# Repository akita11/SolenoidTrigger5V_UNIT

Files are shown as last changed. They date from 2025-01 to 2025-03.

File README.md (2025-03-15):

# SolenoidTrigger5V UNIT

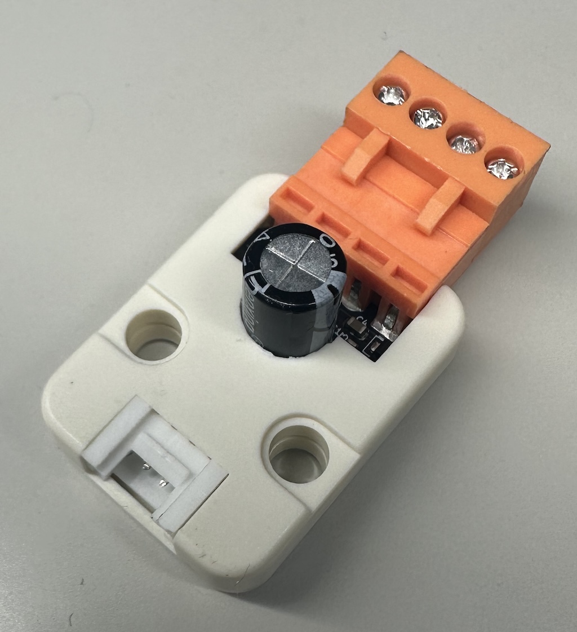
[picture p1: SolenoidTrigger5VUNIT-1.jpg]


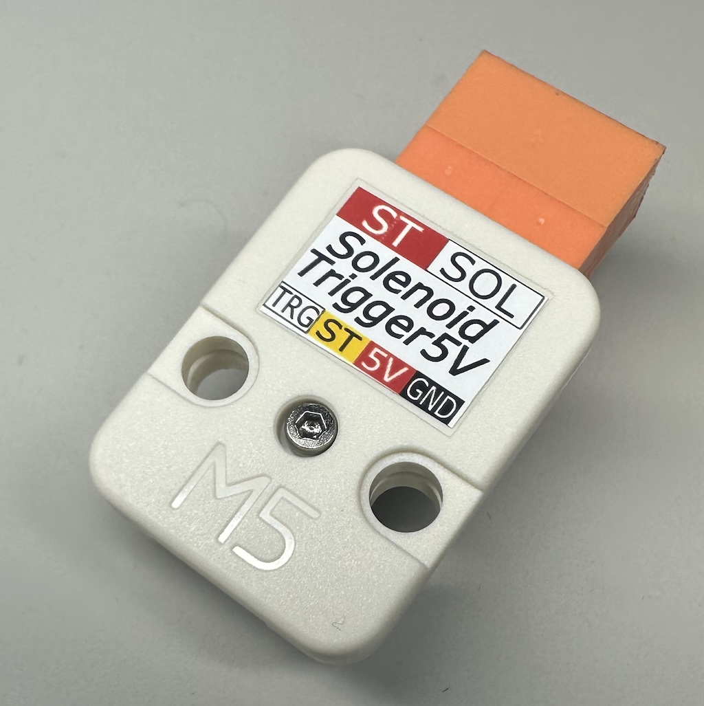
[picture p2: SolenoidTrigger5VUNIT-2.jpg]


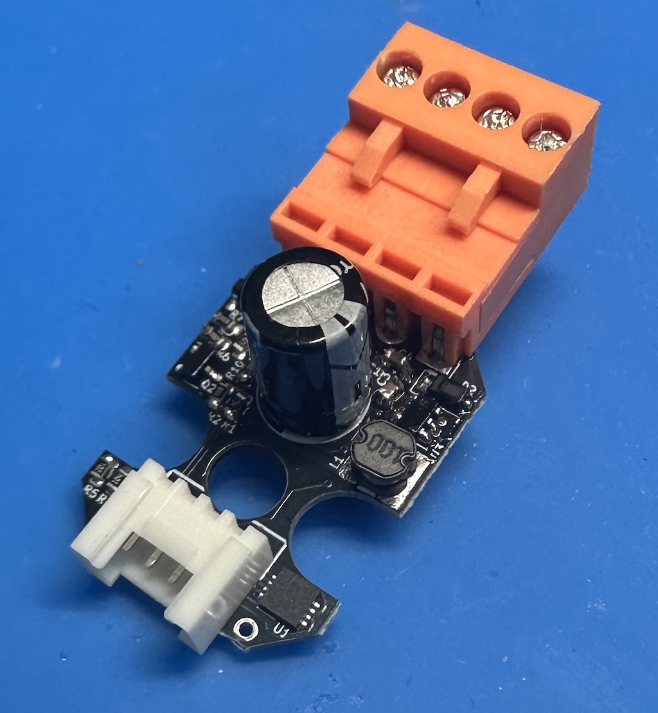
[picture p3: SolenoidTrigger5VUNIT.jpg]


5V電源のみで[タカハのスリムロック](https://www.takaha.co.jp/co/product-slim-lock/)など12V程度以上の高い電圧が必要な負荷を、コンデンサに蓄積したエネルギーで短時間駆動できるユニットです。駆動後は、繰り返しエネルギーを充電して駆動することができます。なおスリムロックの開閉状態をGrove端子から計測するための接続端子もあります。

## 使い方（接続方法）

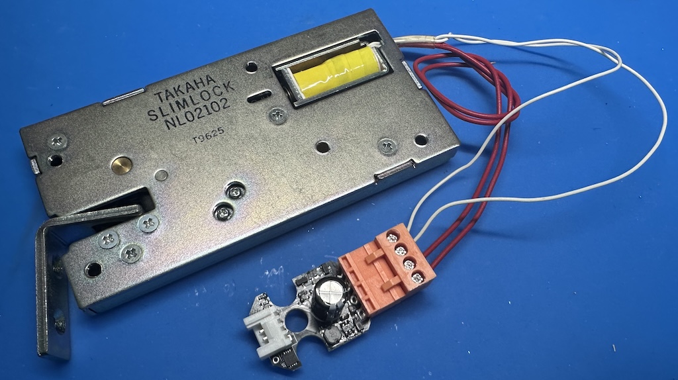
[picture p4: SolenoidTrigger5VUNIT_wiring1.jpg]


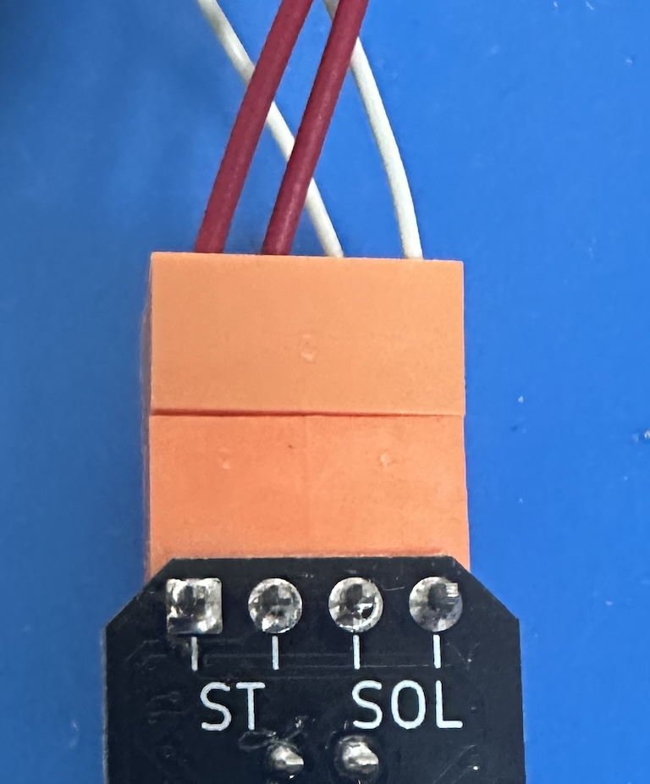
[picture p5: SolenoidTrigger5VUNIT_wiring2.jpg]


オレンジの端子に、以下のように負荷を接続します。
- スリムロックのソレノイド（白ワイヤ）: 基板裏面"SOL"側（極性なし）
- スリムロックの開閉センサ（赤ワイヤ）: 基板裏面"ST"側（極性なし）

Grove端子にはM5Stack等のマイコンに接続します。

## 使い方（ソフトウエア）

Grove端子のp1（コネクタの端側）を駆動信号TRGを"1"にすると、コンデンサに蓄積したエネルギーでスリムロックなどの負荷を一瞬だけ駆動します（施錠状態のスリムロックが解錠されます）。
なお"1"にしてから負荷が駆動されるまでに0.5秒程度時間がかかります。充電動作中はオレンジLEDが点灯し、その間は負荷の駆動が行われません。

Grove端子のp2（コネクタのVDD側）は、ST端子がショート時には"0"、オープン時には"1"となり、Grove端子に接続したM5Stack等のマイコンから読み取ることができます。（内部プルアップ）

### UIFlow(v1)用のカスタムブロック

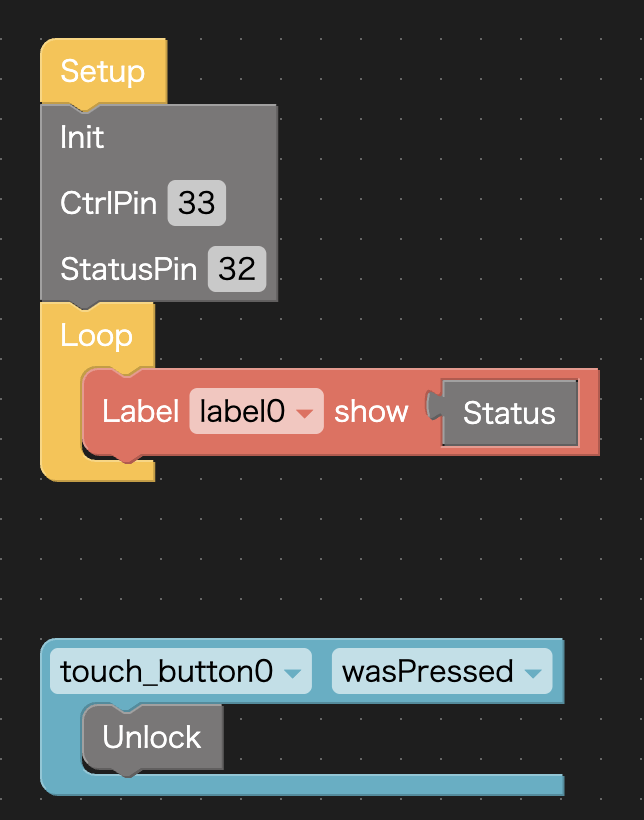
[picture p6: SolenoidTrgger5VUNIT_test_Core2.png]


UIFlow(v1)で、Customから"SolenoidTrigger5V.m5b"を読み込むと、"SolenoidTrigger5VUnit"内の3つのブロックが使えるようになります。（上図はこれを読み込んだあと、"SolenoidTrgger5VUNIT_test_Core2.m5f"を読み込んだ例）

- Init : 解除信号(Groveのp1端子:CtrlPin)とST端子状態(Groveのp2端子:StatusPin)のピン番号を指定します。最初に1回だけ実行します。例：Core2のPortAはp1=GPIO33、p2=GPIO32なので、この図のように指定します。その他の機種・ポートのピン番号は仕様を確認してください。
- Unlock : ロック解除を行います
- Status : ST端子の状態を取得します。スリムロックの場合は、解錠時に"1"、施錠時に"0"になります。

## Author

Junichi Akita (@akita11) / akita@ifdl.jp

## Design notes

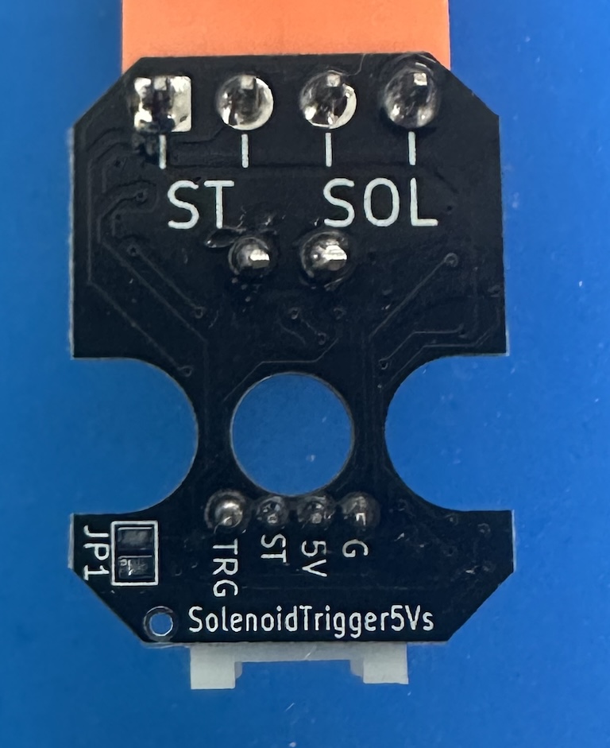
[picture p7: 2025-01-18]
SolenoidTrigger5VUNIT_jumper.jpg

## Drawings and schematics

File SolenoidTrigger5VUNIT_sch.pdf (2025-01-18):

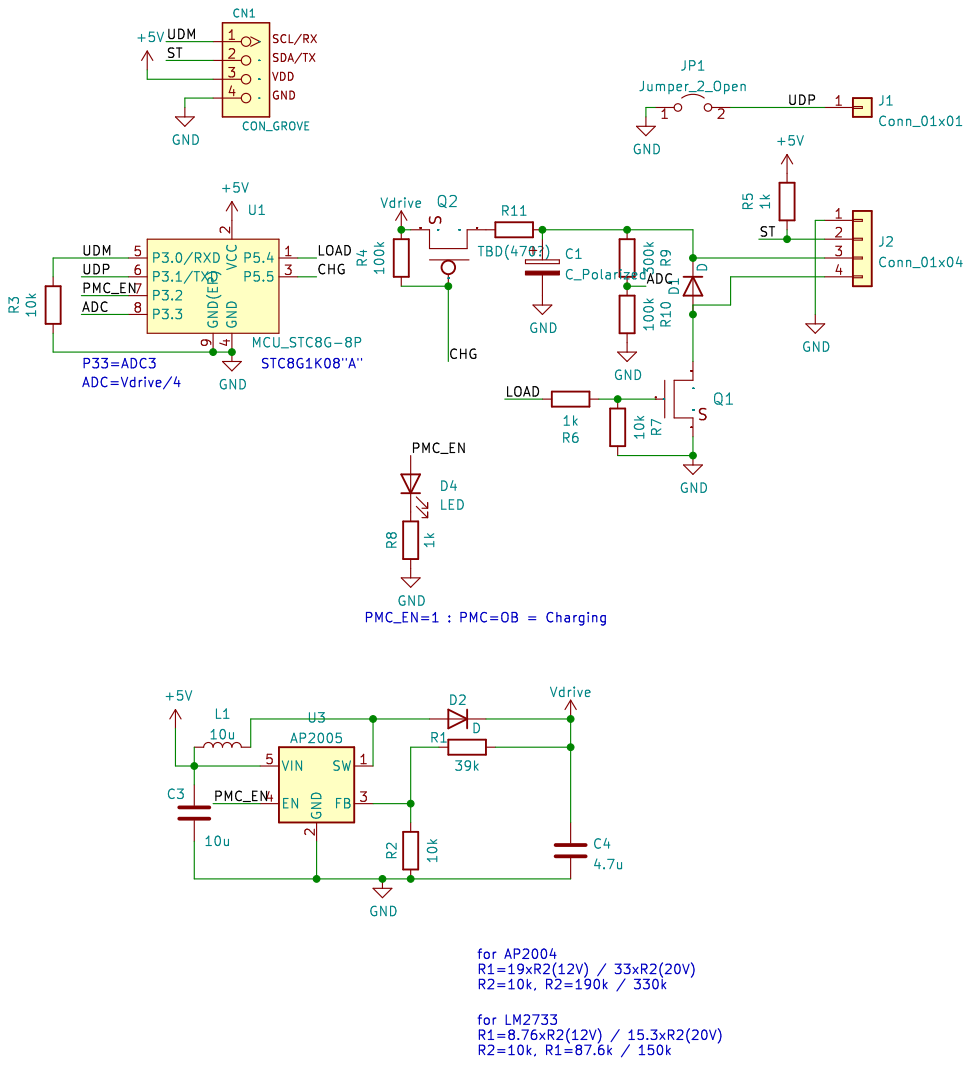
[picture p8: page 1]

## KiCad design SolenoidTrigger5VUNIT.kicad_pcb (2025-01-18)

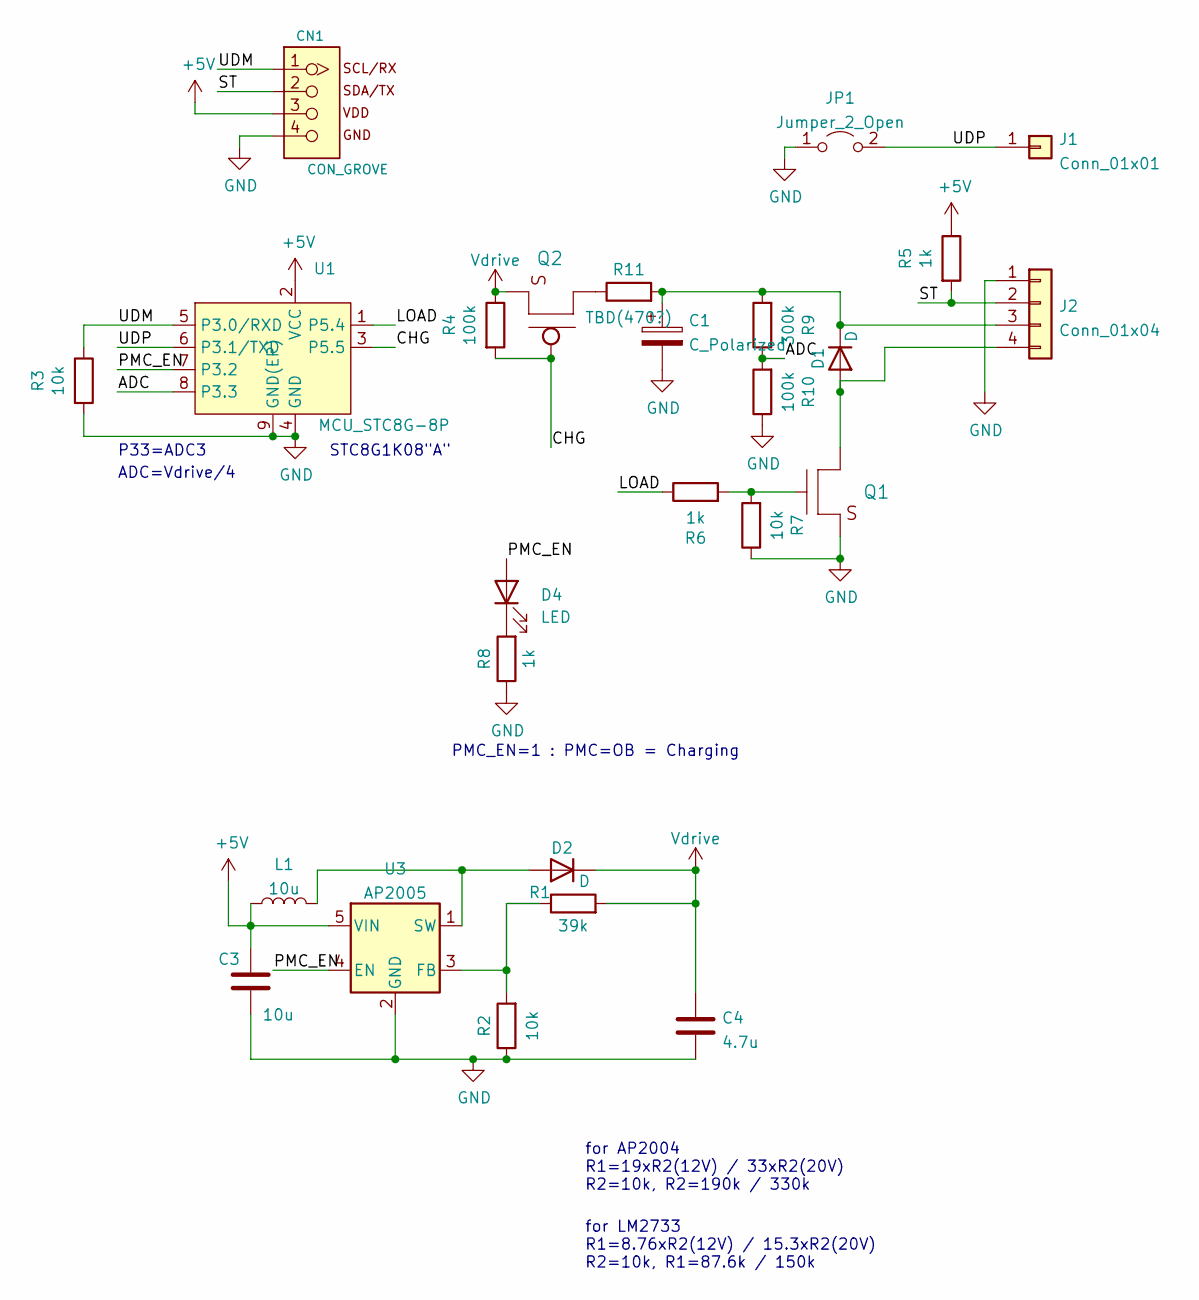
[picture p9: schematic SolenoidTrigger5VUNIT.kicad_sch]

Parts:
C1: C_Polarized; CP_Radial_D8.0mm_P3.50mm
C3: 10u; C_0603_1608Metric; LCSC C96446
C4: 4.7u; C_0603_1608Metric; LCSC C96446
CN1: CON_GROVE; CON_GROVE_H
D1, D2: D; D_SOD-123F; LCSC C2760867
D4: LED; LED_0603_1608Metric; LCSC C165982
J1: Conn_01x01; 1p_TH
J2: Conn_01x04; JST_VH_B4PS-VH_1x04_P3.96mm_Horizontal
JP1: Jumper_2_Open; SolderJumper-2_P1.3mm_Open_Pad1.0x1.5mm
L1: 10u; L_CD43; LCSC C5159664
Q1: TR_NMOS_IRLML6344; SOT-23; LCSC C20917
Q2: TR_PMOS_IRLML6402; SOT-23
R1: 39k; R_0603_1608Metric; LCSC C2907160
R2: 10k; R_0603_1608Metric; LCSC C25804
R3, R7: 10k; R_0603_1608Metric; LCSC C21190
R4, R10: 100k; R_0603_1608Metric; LCSC C21190
R5, R6, R8: 1k; R_0603_1608Metric; LCSC C21190
R9: 300k; R_0603_1608Metric; LCSC C21190
R11: TBD(470?); R_0603_1608Metric; LCSC C21190
U1: MCU_STC8G-8P; DFN-8-1EP_3x3mm_P0.5mm_EP1.65x2.38mm; LCSC C915664
U3: AP2005; SOT-23-6; LCSC C130339

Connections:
+5V: C3.1, CN1.3, L1.1, R5.1, U1.2 (VCC), U3.5 (VIN)
/ADC: R9.1, R10.2, U1.8 (P3.3)
/CHG: Q2.1 (G), R4.2, U1.3 (P5.5)
/LOAD: R6.1, U1.1 (P5.4)
/PMC_EN: D4.2 (A), U1.7 (P3.2), U3.4 (EN)
/ST: CN1.2, J2.2, R5.2
/UDM: CN1.1, R3.1, U1.5 (P3.0/RXD)
/UDP: J1.1, JP1.2 (B), U1.6 (P3.1/TXD)
GND: C1.2, C3.2, C4.2, CN1.4, J2.1, JP1.1 (A), Q1.2 (S), R2.1, R3.2, R7.1, R8.1, R10.1, U1.4 (GND), U1.9 (GND(EP)), U3.2 (GND)
unnamed: C1.1, D1.1 (K), J2.3, R9.2, R11.2
unnamed: D1.2 (A), J2.4, Q1.3 (D)
unnamed: D2.2 (A), L1.2, U3.1 (SW)
unnamed: D4.1 (K), R8.2
unnamed: Q1.1 (G), R6.2, R7.2
unnamed: Q2.3 (D), R11.1
unnamed: R1.1, R2.2, U3.3 (FB)
Vdrive: C4.1, D2.1 (K), Q2.2 (S), R1.2, R4.1

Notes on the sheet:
STC8G1K08"A"
ADC=Vdrive/4
for LM2733 R1=8.76xR2(12V) / 15.3xR2(20V) R2=10k, R1=87.6k / 150k
P33=ADC3
for AP2004 R1=19xR2(12V) / 33xR2(20V) R2=10k, R2=190k / 330k
PMC_EN=1 : PMC=OB = Charging

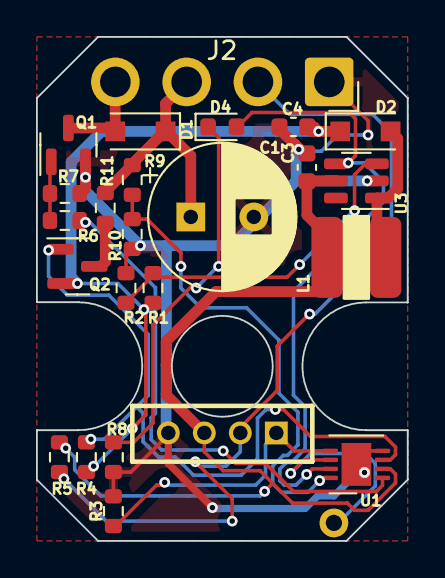
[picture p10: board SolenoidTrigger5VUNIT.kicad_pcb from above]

Board: 2 copper layers, 20.6 x 28.0 mm, 26 parts (1 on the bottom side), 17 nets.

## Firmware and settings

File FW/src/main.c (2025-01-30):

#include <stdint.h>
#include "fw_reg_stc8g.h"

// STC8G1K08A-36I-DFN8
// Grove: RXD(P3.0)-TXD(P3.1)-VDD-GND / RXD for control (1=on / 0=off)

// for SolenoidTrigger5V

#define pinLOAD  P54 // P5.4
#define pinCHG   P55 // P5.5
#define pinRXD   P30 // P3.0 / Grove-p2
#define pinTXD   P31 // P3.1 / outside / mode
#define pinPMCEN P32 // P3.2
#define pinADC   P33 // P3.3 (ADC3)

#define FOSC 11059200UL

uint8_t readVoltage()
{
  // return ADC, 1/4 of Vdrive -> 1/4.9@R9=390k
  ADC_CONTR |= 0x40; // ADC_START=1
  while(ADC_CONTR & 0x40); // wait for ADC_START goes 0 (ADC complete)
  return(ADC_RES); // upper byte
}

void sendByte(unsigned char c)
{
  SBUF = c;
}


void delay100ms(void)	//@11.0592MHz, from STC-ISP
{
  unsigned char i, j, k;
  __asm__("nop");
  i = 6; j = 157; k = 59;
  do { do{ while (--k); } while (--j);} while (--i);
}

void enableCharge(unsigned char d)
{
  if (d == 1){
    P5M1 &= ~0x20; P5M0 |= 0x20; // P5.5=push-pull output
    pinCHG = 0;
  }
  else{
    P5M1 |= 0x20; P5M0 &= ~0x20; // P5.5=analogIN
    pinCHG = 1;
  }
}

void enableDCDC(unsigned char d)
{
  if (d == 1) pinPMCEN = 1;
  else pinPMCEN = 0;
}



void main()
{
  // M1=1/M0=0 : input
  // M1=0/M0=0 : quasi bidirectional
  // M1=0/M0=1 : push-pull output
  P3M1 = 0x09; P3M0 = 0x04; // set P3.1=quasi-bidirectional, P3.2=push-pull, P3.0&3.3=analogIN
  P5M1 = 0x20; P5M0 = 0x10; // set P5.4=push-pull output, P5.5=analogIN
  
  ADC_CONTR = 0x83; // ADC_POW=1, ADC_CHS=0011
  ADCCFG = 0x0f; // RESFMT=0(left align), SPEED=1111 (SYSCLK/2/16)

  /*
  // 9600bpsU(UART1)@11.0592MHz, from STC-ISP
  PCON &= 0x7F;	// Baudrate no doubled
  SCON = 0x50;  // 8 bits and variable baudrate (Mode1), RX enabled
  AUXR |= 0x40; // imer clock is 1T mode
  AUXR &= 0xFE;	// UART 1 use Timer1 as baudrate generator
  TMOD &= 0x0F;	// Set timer work mode
  TMOD |= 0x20;	// Set timer work mode
  TL1 = 0xDC;	// Initial timer value
  TH1 = 0xDC;	// Set reload value
  ET1 = 0;	// Disable Timer%d interrupt
  TR1 = 1;	// Timer1 start run
  */

  pinLOAD = 0;
  enableDCDC(0);
  enableCharge(0);

  //#define TH_CHARGED  197 // 197/255*5*4.9=19V
  //#define TH_TOCHARGE 156 // 156/255*5*4.9=15V
  //#define TH_CHARGED  229 // 229/255*5*4.9=22V
  //#define TH_TOCHARGE 187 // 187/255*5*4.9=18V
  //#define TH_CHARGED  156 // 156/255*5*4.9=15V
  //#define TH_TOCHARGE 104 // 104/255*5*4.9=10V
#define TH_CHARGED  177 // 156/255*5*4.9=17V
#define TH_TOCHARGE 156 // 104/255*5*4.9=15V

  P3 |= 0x02; // enable P3.1 pull-up
  __asm__("nop"); __asm__("nop");
  //  if (pinTXD == 1){

  unsigned char t;
  if (1){
    // JP1=open -> Operation Mode: charge after trigger
    while(1) {
      if (pinRXD == 1){
	enableDCDC(1);
	enableCharge(1);
	t = 0;
	while(readVoltage() < TH_CHARGED && t < 10){
	  delay100ms();
	  t++;
	}
	enableDCDC(0);
	enableCharge(0);
	pinLOAD = 1;
	// Drive Load for 200ms
	delay100ms();
	delay100ms();
	pinLOAD = 0;
	while(pinRXD == 1);
      }
    }
  }
  else{
    // JP1=short -> Operation Mode: charge during idle
    // ** currently disabled due to power charge concern
    while(1) {
      if (readVoltage() < TH_TOCHARGE){
	enableDCDC(1);
	enableCharge(1);
	while(readVoltage() < TH_CHARGED){
	  delay100ms();
	}
	enableDCDC(0);
	enableCharge(0);
      }
      if (pinRXD == 1){
	pinLOAD = 1;
	// Drive Load for 200ms
	delay100ms();
	delay100ms();
	pinLOAD = 0;
	
	while(pinRXD == 1);
      }
    }
  }      
}
